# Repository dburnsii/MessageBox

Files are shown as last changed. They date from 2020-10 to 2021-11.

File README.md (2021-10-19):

<!-- PROJECT SHIELDS -->
<!--
*** I'm using markdown "reference style" links for readability.
*** Reference links are enclosed in brackets [ ] instead of parentheses ( ).
*** See the bottom of this document for the declaration of the reference variables
*** for contributors-url, forks-url, etc. This is an optional, concise syntax you may use.
*** https://www.markdownguide.org/basic-syntax/#reference-style-links
-->
[][contributors-url]
[][forks-url]
[][stars-url]
[][issues-url]
[][license-url]

<!-- PROJECT LOGO -->
<br />
<p align="center">
  <a href="https://github.com/dburnsii/MessageBox">
    <!-- Work in progress  <img src="images/logo.png" alt="Logo" width="80" height="80"> -->
  </a>

  <h3 align="center">MessageBox</h3>

  <p align="center">
    Client-Side application for sharing heartfelt messages
    <br />
    <a href="https://github.com/dburnsii/MessageBox"><strong>Explore the docs »</strong></a>
    <br />
    <br />
    <a href="https://messagebox.unitfi.com">View Demo</a>
    ·
    <a href="https://github.com/dburnsii/MessageBox/issues">Report Bug</a>
    ·
    <a href="https://github.com/dburnsii/MessageBox/issues">Request Feature</a>
  </p>
</p>

<!-- TABLE OF CONTENTS -->
## Table of Contents

* [About the Project](#about-the-project)
  * [Built With](#built-with)
* [Getting Started](#getting-started)
  * [Prerequisites](#prerequisites)
  * [Installation](#installation)
* [Usage](#usage)
* [Roadmap](#roadmap)
* [Contributing](#contributing)
* [License](#license)
* [Contact](#contact)
* [Acknowledgements](#acknowledgements)

<!-- ABOUT THE PROJECT -->
## About The Project

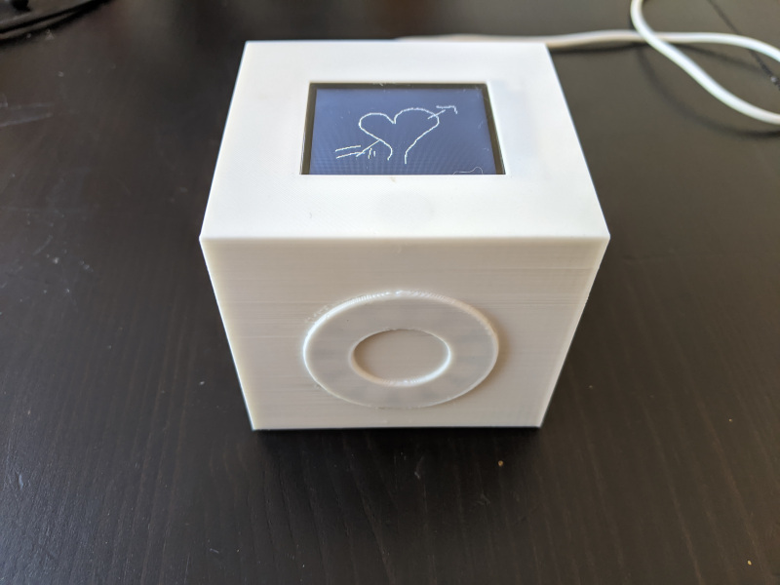
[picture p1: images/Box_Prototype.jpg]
Prototype (https://messagebox.unitfi.com)


This project serves as the client application for the MessageBox project. MessageBox allows you to easily
send messages to friends or loved ones with a simple and easy to use interface. The messages are
sent to the MessageBox hardware, and the user on the other end is notified of the new message. After
opening the box and reading the message, the box clears it's screen and listens for more messages.
This provides a clean interface to send personal messages to someone at work or home, without distracting
the recipient or requiring them to use any complex technology.

### Built With

* [PlatformIO](https://platformio.org/)

<!-- GETTING STARTED -->
## Getting Started

To get a MessageBox up and running follow these steps.

### Prerequisites

#### Hardware

You'll need the following:
* 3D Printed Parts in the `CAD_Files/FreeCAD` folder
* PCB in the `CAD_Files/KiCad` folder
* Off-the-shelf parts listed in `BOM.md`
* Soldering Iron and Solder
* (*Optional*)  Heatshrink Tubing
* (*Optional*)  Hot Glue Gun

#### Software

You'll need the following:
* PlatformIO

### Installation

1. To run the project, build and upload with PlatformIO:
```sh
pio run
pio run -t uploadfs
pio run -t upload
```

The uploadfs command will ensure all necessary SSL certificates are installed on the system, for use with HTTPS.

<!-- USAGE EXAMPLES -->
## Usage

Setup instructions will appear on the TFT LCD attached to the box.

<!-- ROADMAP -->
## Roadmap

See the [open issues](https://github.com/dburnsii/MessageBox/issues) for a list of proposed features (and known issues).

<!-- CONTRIBUTING -->
## Contributing

Contributions are what make the open source community such an amazing place to be learn, inspire, and create. Any contributions you make are **greatly appreciated**.

1. Fork the Project
2. Create your Feature Branch (`git checkout -b feature/AmazingFeature`)
3. Commit your Changes (`git commit -m 'Add some AmazingFeature'`)
4. Push to the Branch (`git push origin feature/AmazingFeature`)
5. Open a Pull Request

<!-- LICENSE -->
## License

Distributed under the MIT License. See `LICENSE` for more information.

<!-- CONTACT -->
## Contact

Desone Burns II - dburnsii@live.com

Project Link: [https://github.com/dburnsii/MessageBox](https://github.com/dburnsii/MessageBox)

<!-- ACKNOWLEDGEMENTS
## Acknowledgements

* []()
* []()
* []()

-->

<!-- MARKDOWN LINKS & IMAGES -->
<!-- https://www.markdownguide.org/basic-syntax/#reference-style-links -->
[contributors-shield]: https://img.shields.io/github/contributors/dburnsii/MessageBox.svg?style=flat-square
[contributors-url]: https://github.com/dburnsii/MessageBox/graphs/contributors
[forks-shield]: https://img.shields.io/github/forks/dburnsii/MessageBox.svg?style=flat-square
[forks-url]: https://github.com/dburnsii/MessageBox/network/members
[stars-shield]: https://img.shields.io/github/stars/dburnsii/MessageBox.svg?style=flat-square
[stars-url]: https://github.com/dburnsii/MessageBox/stargazers
[issues-shield]: https://img.shields.io/github/issues/dburnsii/MessageBox.svg?style=flat-square
[issues-url]: https://github.com/dburnsii/MessageBox/issues
[license-shield]: https://img.shields.io/github/license/dburnsii/MessageBox.svg?style=flat-square
[license-url]: https://github.com/dburnsii/MessageBox/blob/master/LICENSE
[product-screenshot]: public/images/screenshot.png

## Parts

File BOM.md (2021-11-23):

# Bill of Materials

| Name | Description | Link | Image |
| ---- | --- | ---- | ---- |
| D1 Mini NodeMCU (x1) | Main MCU used to control all MessageBox functionality | [eBay](https://www.ebay.com/itm/D1-Mini-NodeMCU-and-Arduino-WiFi-LUA-ESP8266-ESP-12-WeMos-Microcontroller/113845558271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) | D1 Mini NodeMCU |
| ST7735S 128x160 TFT Display (x1) | LCD Display used for showing messages | [eBay](https://www.ebay.com/itm/1-8-inch-TFT-Display-module-ST7735S-128x160-QVGA-Arduino-128-160-lcd-1-8/322573886048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)| TFT LCD |
| Adafruit Neopixel Ring (12 LED) (x1) | Displays information to the user when the lid is closed | [AdaFruit](https://www.adafruit.com/product/1643) | Neopixel Ring |
| Magnetic Reed Switch (x1) | Detects when the Box has been opened | [eBay](https://www.ebay.com/itm/10Cs-MKA-14103-Lead-Glass-N-O-Spst-Reed-Switch-10-15AT-2-X-14Mm-ci/252895705159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) | Reed Switch |
| 10mm x 1.5mm Round Neodymium Magnets (x3) | Triggers the reed switch and keeps lid in place | [eBay](https://www.ebay.com/itm/50-100PCS-3-8-x-1-16-Neodymium-Magnets-Round-Disc-Bottle-Cap-Magnet-Fridge-N50/174385882900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) | Magnets
| 8-Pin JST-XH2.54 Headers (x2) and Connector | Connects the TFT Display to the PCB | [eBay](https://www.ebay.com/itm/10Sets-JST-XH2-54-XH-2-54mm-Wire-Cable-Connector-2-3-4-5-6-7-8-9-10-Pin-Pitch/264637792461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) | JST Connector
| 3-Pin JST-XH2.54 Headers (x1) and Connector | Connects the Neopixel Ring to the PCB | [eBay](https://www.ebay.com/itm/10Sets-JST-XH2-54-XH-2-54mm-Wire-Cable-Connector-2-3-4-5-6-7-8-9-10-Pin-Pitch/264637792461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) | JST Connector
| 2-Pin JST-XH2.54 Headers (x1) and Connector | Connects the Magnetic Reed Switch to the PCB | [eBay](https://www.ebay.com/itm/10Sets-JST-XH2-54-XH-2-54mm-Wire-Cable-Connector-2-3-4-5-6-7-8-9-10-Pin-Pitch/264637792461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) | JST Connector
| 330 Ohm 0805 SMD Resistor (x3) | Used to regulate voltage to the Neopixel Ring and to pull-down the Reed Switch | [eBay](https://www.ebay.com/itm/100pcs-0805-330K-Ohm-1-8W-1-8-Watt-1-Resistor-US-Seller/252738205032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) | Resistor |

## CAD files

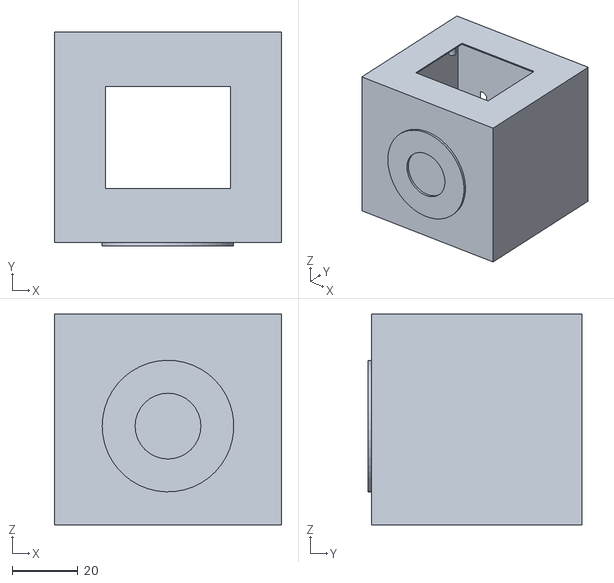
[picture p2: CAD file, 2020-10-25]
CAD_Files/FreeCAD/MessageboxBody.stl
69.0 x 65.0 x 64.0

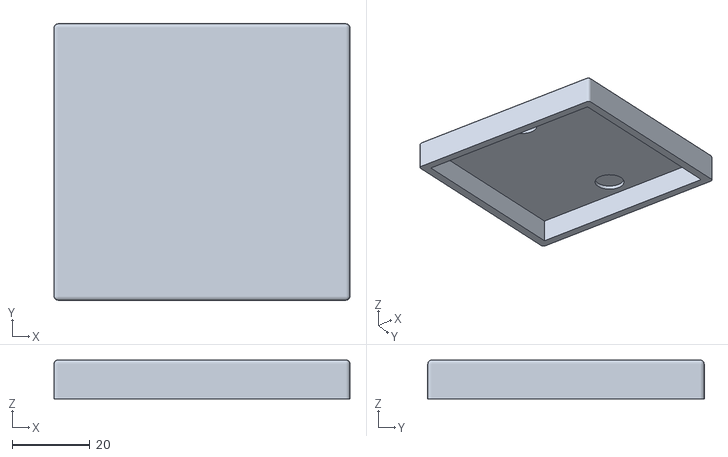
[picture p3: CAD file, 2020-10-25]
CAD_Files/FreeCAD/MessageboxLid.stl
76.0 x 71.0 x 10.0

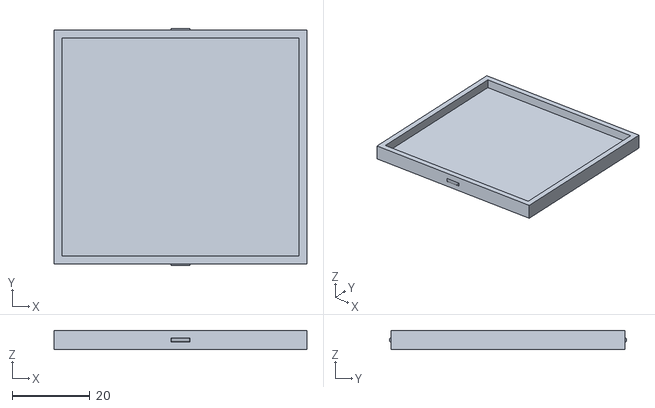
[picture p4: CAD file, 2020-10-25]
CAD_Files/FreeCAD/MessageboxBottom.stl
65.0 x 61.0 x 5.00

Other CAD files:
CAD_Files/FreeCAD/MessageBox.FCStd

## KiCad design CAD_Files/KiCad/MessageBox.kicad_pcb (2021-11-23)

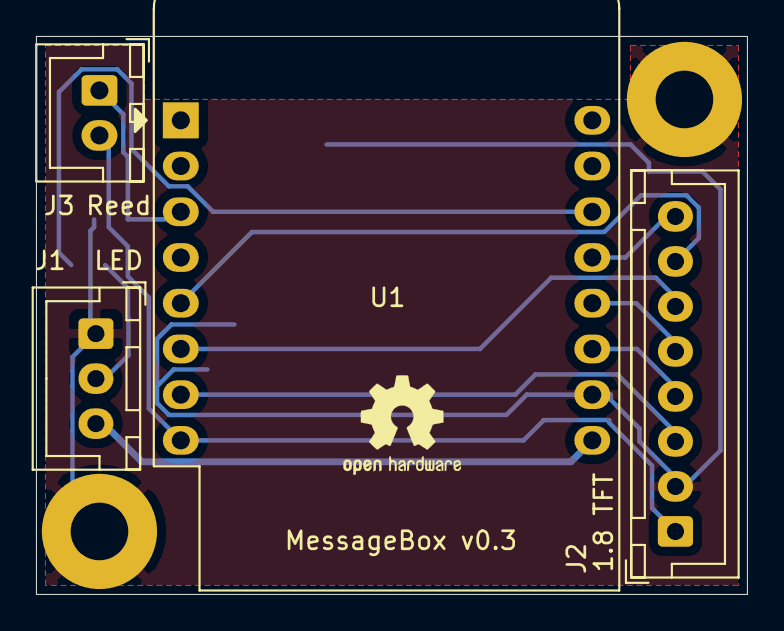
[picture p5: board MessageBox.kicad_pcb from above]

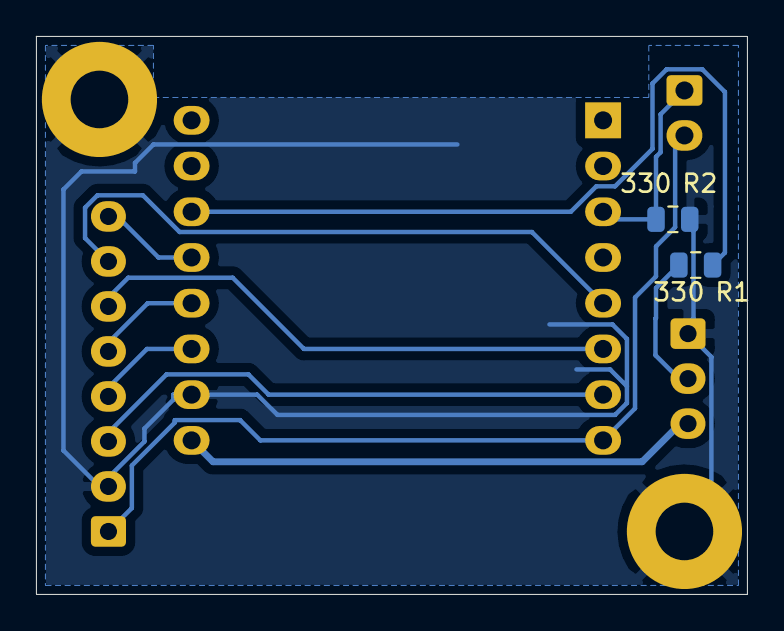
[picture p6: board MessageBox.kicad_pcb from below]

Board: 2 copper layers, 39.5 x 31.0 mm, 6 parts (2 on the bottom side), 12 nets.

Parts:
J1: Conn_01x03_Female; JST_XH_B3B-XH-A_1x03_P2.50mm_Vertical
J2: 1.8 TFT; JST_XH_B8B-XH-A_1x08_P2.50mm_Vertical
J3: Reed Switch; JST_XH_B2B-XH-A_1x02_P2.50mm_Vertical
R1, R2: 330; R_0805_2012Metric
U1: WeMos_D1_mini; WEMOS_D1_mini_light

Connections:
+3V3: J2.1, J3.2, U1.8
+5V: J1.3, U1.9
GND: J1.1, J2.2, R2.1, U1.10
unnamed: J1.2, R1.1
unnamed: J2.3, U1.7
unnamed: J2.4, U1.11
unnamed: J2.5, U1.12
unnamed: J2.6, U1.6
unnamed: J2.7, U1.5
unnamed: J2.8, U1.13
unnamed: J3.1, R2.2, U1.3
unnamed: R1.2, U1.14

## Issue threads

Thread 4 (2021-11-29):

Add box reset mechanism

dburnsii, 2021-11-29:
Inevitably, a box will need to be reset. Add a mechanism using the available inputs (power, lid open) to create some sequence that will reset a box (delete the user id and authentication key).

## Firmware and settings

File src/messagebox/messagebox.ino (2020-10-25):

#define ESP8266

#include <Adafruit_GFX.h>    // Core graphics library
#include <Adafruit_ST7735.h> // Hardware-specific library for ST7735
#include <Adafruit_NeoPixel.h> // LED Ring library
#include <SPI.h>
#include <Ticker.h>

#include <ESP8266WiFi.h>
#include <ESP8266HTTPClient.h>
#include <ESP8266WebServer.h>
#include <AutoConnect.h>
#include <CertStoreBearSSL.h>
#include <time.h>
#include <FS.h>

// LED Ring pin and count
#define LED_PIN D1
#define LED_COUNT 12

// Screen dimensions and pin assignments
#define HEIGHT 128
#define WIDTH 160
#define LID D0
#define BACKLIGHT D2
#define TFT_CS         D8
#define TFT_RST        D4
#define TFT_DC         D3
Adafruit_ST7735 tft = Adafruit_ST7735(TFT_CS, TFT_DC, TFT_RST);

#define AUTOCONNECT_URI         "/_ac/config"

// Debug mode, prints messages to the Serial port
#define DEBUG 1

// Neopixel ring instance
Adafruit_NeoPixel ring(LED_COUNT, LED_PIN, NEO_GRB + NEO_KHZ800);

// WiFi specific variables
ESP8266WebServer Server;
BearSSL::WiFiClientSecure *bearSSL;
BearSSL::CertStore certStore;
HTTPClient client;
AutoConnect Portal(Server);
AutoConnectConfig PortalConfig;
boolean serverAvailable = true;
boolean wifiConnected = false;
String host = "messagebox.unitfi.com";
const char * headerKeys[] = {"user", "code", "Content-Type", "status"};
const size_t numberOfHeaders = 4;

// Name of file to save image to
String imageName = "/message.tft";

// Unique 32-byte key generated by box for authentication
String key;

// User ID from server for retrieving message. Presence of user indicates 
// we've registered with the server
String user;

// One-time activation code used to register the box
String code;

// Indicates if we've already completed some action for the lid opening, preventing
// multiple screen writes, clearing messages right away, etc
boolean state = false;

// Interrupt and corresponding variables for rate-limiting
Ticker timer;
volatile int httpCheck = 0;
volatile int lidCheck = 0;
volatile int ledCheck = 0;

// Function declarations
void onTime();
void setClock();
void downloadMessage();
void displayWiFiLogin();
void displayConnecting();
void displayWiFiConnected();
void displayActivationCode();
void displayNoServer();
void displayMessage();
void drawHeart(int, int);


void resetBox() {
  SPIFFS.remove("/key.txt");
  SPIFFS.remove("/user.txt");
  ESP.restart();
}

void setup(void)
{
  if(DEBUG){
    Serial.begin(9600);
    Serial.println("Starting messagebox");
  }

  // Start LED Ring, assigning random colors to each LED during setup
  ring.begin();
  uint32_t color = ring.Color(15, 15, 255);
  for(int i=0; i<ring.numPixels(); i++){
    color = ring.Color(random(255), random(255), random(255));
    ring.setPixelColor(i,color);
  }
  ring.setBrightness(16);
  ring.show();

  //Intitialize the lcd screen, and show "splash screen"
  pinMode(BACKLIGHT, OUTPUT);
  pinMode(LID, INPUT);
  tft.initR(INITR_BLACKTAB);
  tft.setRotation(1);
  tft.fillScreen(ST77XX_BLACK);
  tft.setTextColor(0xFFFF);
  tft.setCursor(50, 60);
  tft.print("MessageBox");
  digitalWrite(BACKLIGHT, HIGH);
  delay(3000);

  // Initialize timer for lcd and http
  timer1_attachInterrupt(onTime);
  timer1_enable(TIM_DIV256, TIM_EDGE, TIM_LOOP); // 80MHz Base / 256 = 312.5KHz -> 3.2us
  timer1_write(3125);  // 3.2us * 3125 ~= 10000us -> 10ms

  // Inform the user we're attempting to connect to WiFi
  displayConnecting();

  // Start the wifi autoconnect service
  PortalConfig.apid = "Messagebox";
  PortalConfig.bootUri = AC_ONBOOTURI_HOME;
  PortalConfig.homeUri = "/_ac/config";
  PortalConfig.psk = "";
  PortalConfig.portalTimeout = 1;
  PortalConfig.retainPortal = true;
  Portal.config(PortalConfig);
  Portal.begin();

  // Wait for the box to be connected to WiFi, informing user of how to log in
  while(WiFi.status() != WL_CONNECTED){
    displayWiFiLogin();
    Portal.handleClient();
    delay(100);
  }

  // Bring down the Access Point
  if(DEBUG){Serial.println("Successfully connected to WiFi");}
  WiFi.softAPdisconnect(true);
  displayWiFiConnected();

  // Prepare clock and SSL Certificates
  if(DEBUG){Serial.println("Preparing SSL");}
  setClock();

  // Clear the screen and draw a heart
  tft.fillScreen(ST77XX_BLACK);
  drawHeart((160 / 2) - 8, (128/2) - 8);

  // Start filesystem for Authentication credentials and SSL Certs
  SPIFFS.begin();

  int numCerts = certStore.initCertStore(SPIFFS, PSTR("/certs.idx"), PSTR("/certs.ar"));
  if(DEBUG){Serial.printf("Certs read: %d\n", numCerts);}
  
  if(numCerts == 0) {
    if(DEBUG){Serial.println("Missing certs!");}
    // TODO: Inform the user with what has actually gone wrong. This usually 
    // happens when certs have not been loaded into the filesystem
    return;
  }

  bearSSL = new BearSSL::WiFiClientSecure();
  bearSSL->setCertStore(&certStore);


  // Check if a generated key exists. If it does not exist,
  // Create a new one (randomly generated 32-byte key)
  if (SPIFFS.exists("/key.txt"))
  {
    File keyFile = SPIFFS.open("/key.txt", "r");
    key = keyFile.readString();
    keyFile.close();
  } else {
    key = "";
    int i = 0;
    for( int i = 0; i < 32; i++)
    {
      key += String(random(255), HEX);
    }
    File keyFile = SPIFFS.open("/key.txt", "w");
    keyFile.print(key);
    keyFile.close();
  }

  // Check if we have a User ID saved. Presence of User ID 
  // indicates we've successfully been registered.
  if (SPIFFS.exists("/user.txt"))
  {
    File userFile = SPIFFS.open("/user.txt", "r");
    user = userFile.readString();
  }
  else
  {
    user = "";
  }
}

void loop(void)
{
  // Run screen and LED Ring functions
  if(lidCheck >= 5){
    lidCheck = 0;
    if(digitalRead(LID) == LOW){
      ring.setBrightness(0);
      ring.show();
      // If we haven't already completed some action for this instance of the lid being removed,
      // Try to display a message first. If there is no message, show any other issues, otherwise
      // Show a heart to indicate the box is active but there is nothing to do.
      if(!state){
        if(SPIFFS.exists(imageName)){
          if(DEBUG){Serial.println("Displaying Message.");}
          displayMessage();
          SPIFFS.remove(imageName);
          ring.setBrightness(0);
          ring.show();
        } else if(user == "" && code != "") {
          displayActivationCode();
          if(DEBUG){Serial.println("Unit not activated. Displaying activation code.");}
        } else if(!serverAvailable){
          displayNoServer();
          if(DEBUG){Serial.println("Server not available.");}
        } else {
          tft.fillScreen(ST77XX_BLACK);
          drawHeart((160 / 2) - 8, (128/2) - 8);
          if(DEBUG){Serial.println("Nothing to display.");}
        }
      }
      state = true;
      digitalWrite(BACKLIGHT, HIGH);
    } else {
      // Lid is on, turn the backlight off
      digitalWrite(BACKLIGHT, LOW);
      state = false;
    }
  }
 
  if(httpCheck >= 100){    
    if(SPIFFS.exists(imageName)){
      //We have a message waiting to be read. Do nothing.
      httpCheck = 0;
    } else if(user != "") {
      // Begin asking the server if we have any new messages
      client.begin(*bearSSL, String("https://" + host + "/message/read") +
                      "?key=" + key +
                      "&user=" + user);
      client.collectHeaders(headerKeys, numberOfHeaders);
      int httpCode = client.GET();

      if(httpCode >= 200 && httpCode <= 299){
        serverAvailable = true;
        if(DEBUG){Serial.println("Successfully contacted server");}
      } else {
        serverAvailable = false;
        if(DEBUG){Serial.println("Server contact failure: " + String(httpCode));}
      }

      // Check status and react accordingly
      if(client.hasHeader("status")){
        String status = client.header("status");
        if(status == "No Messages"){
          //No message, do nothing.
          if(DEBUG){Serial.println("No Messages.");}
        } else if(status == "New Message" && client.header("Content-Type") == "application/octet-stream"){
          downloadMessage();
          uint32_t color = ring.Color(15, 15, 255);
          for(int i=0; i<ring.numPixels(); i++){
            ring.setPixelColor(i,color);
          }
          ring.setBrightness(64);
          ring.show();
        } else if(status == "No Box"){
          if(DEBUG){Serial.println("Resetting box");}
          resetBox();
        } else if(status == "Update"){
          if(DEBUG){Serial.println("System update");}
          //Update system
        }
      }
      client.end();
    } else {
      // We haven't authenticated yet, send credentials to server until
      // we get a user id
      client.begin(*bearSSL, String("https://" + host + "/box/activate") +
                      "?key=" + key);

      client.collectHeaders(headerKeys, numberOfHeaders);
      int httpCode = client.GET();

      if(httpCode >= 200 && httpCode <= 299){
        serverAvailable = true;
        if(DEBUG){Serial.println("Successfully contacted server");}
      } else {
        serverAvailable = false;
        if(DEBUG){Serial.println("Server contact failure: " + String(httpCode));}
      }

      // Check activation headers:
      // If "code", display the activation code
      // If "user", we've been acivated and assigned to a user,
      //    so save that information.
      if(client.hasHeader("code") && code == ""){
        code = client.header("code");
        state = false;
      } else if(client.hasHeader("user")){
        user = client.header("user");
        state = false;
      } else if(client.hasHeader("reset")){
        resetBox();
      }

      client.end();
    }
  }
  delay(5);
}

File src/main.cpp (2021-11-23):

#include <Ticker.h>
#include <Wire.h>
#include <LittleFS.h>
#include <base64.h>

#include <SPI.h>

#include <Adafruit_GFX.h>    // Core graphics library
#include <Adafruit_ST7735.h> // Hardware-specific library for ST7735
#include <Adafruit_NeoPixel.h> // LED Ring library

#include <ESP8266WiFi.h>
#include <ESP8266HTTPClient.h>
#include <ESP8266WebServer.h>
#include <ESP8266httpUpdate.h>
#include <AutoConnect.h>
#include <CertStoreBearSSL.h>
#include <time.h>

// LED Ring pin and count
#define LED_PIN D1
#define LED_COUNT 12

// Screen dimensions and pin assignments
#define HEIGHT 128
#define WIDTH 160
#define LID D0
#define BACKLIGHT D2
#define TFT_CS         D8
#define TFT_RST        D4
#define TFT_DC         D3  // Also A0 on the TFT board
Adafruit_ST7735 tft = Adafruit_ST7735(TFT_CS, TFT_DC, TFT_RST);

#undef AUTOCONNECT_URI
#define AUTOCONNECT_URI         "/_ac/config"

// Neopixel ring instance
Adafruit_NeoPixel ring(LED_COUNT, LED_PIN, NEO_GRB + NEO_KHZ800);

// WiFi specific variables
ESP8266WebServer Server;
BearSSL::CertStore certStore;
HTTPClient http;
AutoConnect Portal(Server);
AutoConnectConfig PortalConfig;
boolean serverAvailable = true;
boolean wifiConnected = false;

// If running in debug mode, opt for using http over https
#ifdef DEBUG
  #pragma message ( "Building in Debug mode. HTTPS disabled." )
  WiFiClient *client;
  String protocol = "http://";
#else
  BearSSL::WiFiClientSecure *client;
  String protocol = "https://";
#endif

// Set the address to make http requests to
#ifdef HOST_ADDRESS
  #pragma message(HOST_ADDRESS)
  String host = HOST_ADDRESS;
#else
  #pragma message("Using default host address")
  String host = "messagebox.unitfi.com";
#endif

// Set the current version of firmware, and default to 0.0.0
#ifdef FIRMWARE_VERSION
  String version = FIRMWARE_VERSION;
#else
  #error "Firmware version not defined! Set the FIRMWARE_VERSION environment variable and try again."
#endif

const char * headerKeys[] = {"user", "code", "Content-Type", "status"};
const size_t numberOfHeaders = 4;

// Name of file to save image to
String imageName = "message.tft";

// Unique 32-byte key generated by box for authentication
// TODO: Deprecate the key string in favor of the binary version
String key;
uint8_t key_bin[32];

// User ID from server for retrieving message. Presence of user indicates
// we've registered with the server
String user;

// One-time activation code used to register the box
String code;

// Indicates if we've already completed some action for the lid opening, preventing
// multiple screen writes, clearing messages right away, etc
boolean state = false;

// Interrupt and corresponding variables for rate-limiting
Ticker timer;
volatile int httpCheck = 0;
volatile unsigned long updateCheck = 0;
volatile int lidCheck = 0;
volatile int ledCheck = 0;

// Function declarations
void onTime();
void setClock();
void downloadMessage();
void displayWiFiLogin();
void displayConnecting();
void displayWiFiConnected();
void displayActivationCode();
void displayNoServer();
void displayMessage();
void drawHeart(int, int);


void resetBox() {
  LittleFS.remove("key.txt");
  LittleFS.remove("user.txt");
  ESP.restart();
}

void setup(void)
{
  #ifdef DEBUG
    Serial.begin(9600);
    Serial.println("Starting messagebox");
    Serial.println(FIRMWARE_VERSION);
  #endif

  // Start LED Ring, assigning random colors to each LED during setup
  ring.begin();
  uint32_t color = ring.Color(15, 15, 255);
  for(int i=0; i<ring.numPixels(); i++){
    color = ring.Color(random(255), random(255), random(255));
    ring.setPixelColor(i,color);
  }
  ring.setBrightness(1);
  ring.show();

  //Intitialize the lcd screen, and show "splash screen"
  pinMode(BACKLIGHT, OUTPUT);
  pinMode(LID, INPUT);
  tft.initR(INITR_BLACKTAB);
  tft.setRotation(1);
  tft.fillScreen(ST77XX_BLACK);
  tft.setTextColor(0xFFFF);
  tft.setCursor(50, 60);
  tft.print("MessageBox");
  digitalWrite(BACKLIGHT, HIGH);
  delay(3000);

  // Initialize timer for lcd and http
  timer1_attachInterrupt(onTime);
  timer1_enable(TIM_DIV256, TIM_EDGE, TIM_LOOP); // 80MHz Base / 256 = 312.5KHz -> 3.2us
  timer1_write(3125);  // 3.2us * 3125 ~= 10000us -> 10ms

  // Inform the user we're attempting to connect to WiFi
  displayConnecting();

  // Start the wifi autoconnect service
  PortalConfig.apid = "Messagebox";
  PortalConfig.bootUri = AC_ONBOOTURI_HOME;
  PortalConfig.homeUri = "/_ac/config";
  PortalConfig.psk = "";
  PortalConfig.portalTimeout = 1;
  PortalConfig.retainPortal = true;
  Portal.config(PortalConfig);
  Portal.begin();

  // Wait for the box to be connected to WiFi, informing user of how to log in
  displayWiFiLogin();
  while(WiFi.status() != WL_CONNECTED){
    Portal.handleClient();
    delay(100);
  }

  // Bring down the Access Point
  #ifdef DEBUG
    Serial.println("Successfully connected to WiFi");}
  #endif
  WiFi.softAPdisconnect(true);
  displayWiFiConnected();

  // Prepare clock and SSL Certificates
  #ifdef DEBUG
    Serial.println("Preparing SSL");}
  #endif
  setClock();

  // Clear the screen and draw a heart
  tft.fillScreen(ST77XX_BLACK);
  drawHeart((160 / 2) - 8, (128/2) - 8);

  // Start filesystem for Authentication credentials and SSL Certs
  LittleFS.begin();

  int numCerts = certStore.initCertStore(LittleFS, PSTR("certs.idx"), PSTR("certs.ar"));

  if(numCerts == 0) {
    #ifdef DEBUG
      Serial.println("Missing certs!");}
    #endif
    // TODO: Inform the user with what has actually gone wrong. This usually
    // happens when certs have not been loaded into the filesystem
    return;
  }

  #ifdef DEBUG
    client = new WiFiClient();
  #else
    client = new BearSSL::WiFiClientSecure();
    client->setCertStore(&certStore);
    client->setInsecure();
  #endif

  // Check if a generated key exists. If it does not exist,
  // Create a new one (randomly generated 32-byte key)
  if (LittleFS.exists("key.txt"))
  {
    File keyFile = LittleFS.open("key.txt", "rb");
    for( int i = 0; i < 32; i++)
    {
      key_bin[i] = keyFile.read();
      key += String(key_bin[i], HEX);
    }
    keyFile.close();
  } else {
    key = "";
    for( int i = 0; i < 32; i++)
    {
      uint8_t c = random(255);
      key += String(c, HEX);
      key_bin[i] = c;
    }
    File keyFile = LittleFS.open("key.txt", "wb");
    keyFile.write(key_bin, 32);
    keyFile.close();
  }

  // Check if we have a User ID saved. Presence of User ID
  // indicates we've successfully been registered.
  if (LittleFS.exists("user.txt"))
  {
    File userFile = LittleFS.open("user.txt", "r");
    user = userFile.readString();
  }
  else
  {
    user = "";
  }
}
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

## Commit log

2020-06-15 Shows message on screen with lid sensor
2020-07-16 Added BOM, Updated to ST7735
2020-07-16 Added Initial CAD File
    [MessageBoxBody.FCStd]
2020-08-08 Added PCBs, switch to images
    [MessageBox.kicad_pcb]
2020-10-25 Update code, update CAD files
    [MessageBox.FCStd, MessageBox.kicad_pcb, MessageBox.sch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]
2020-10-30 Switch to PlatformIO
2020-10-30 Update README and fix http refresh
    [main.cpp]
2020-11-02 Update BOM and Readme
2021-11-23 Updated board, fixes for build, added debug logic
    [MessageBox.kicad_pcb, MessageBox.sch]
